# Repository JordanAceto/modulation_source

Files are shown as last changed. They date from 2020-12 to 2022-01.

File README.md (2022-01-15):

# Eurorack Modulation Source



## [SCHEMATIC](https://github.com/JordanAceto/modulation_source/blob/main/main_pcb/construction_docs/modulation_source_schematic.pdf)

## Features:
- Sine and Square wave voltage controlled LFO
- LED indicator shown the LFO speed
- White and Pink noise source
- Sample and Hold
- Convenient normalization
    - LFO square wave normalled to the S&H clock input
    - White noise normalled to the S&H signal input
- There is a pcb front panel, for a cheap and cheerful panel option

## Errata:
- The pink noise gain is a little hot, change R30 to around 39k to bring the pink noise level down if desired

## Status of the project:

Task | Status |
---------|--------------|
Schematic capture | &#9745;
PCB layout | &#9745;
Test build | &#9745;
Safe to order boards| &#9745;

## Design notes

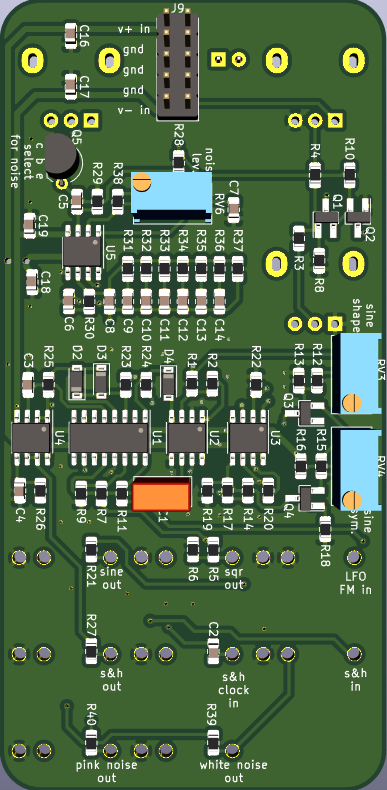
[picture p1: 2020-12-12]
main_pcb/pics/pcb_rear.png

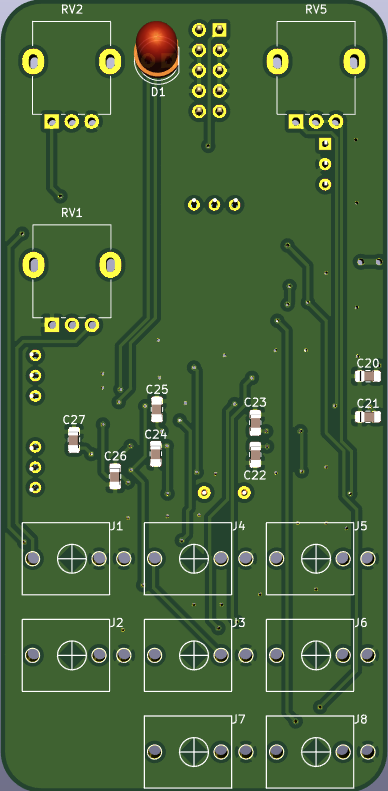
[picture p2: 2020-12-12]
main_pcb/pics/pcb_front.png

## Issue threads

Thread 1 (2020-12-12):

pink noise gain is too high

JordanAceto, 2020-12-12:
The gain of the pink noise filter opamp is too high. reduce R37 so that the peak to peak amplitude of the pink noise is roughly equal to the peak to peak amplitude of the white noise.

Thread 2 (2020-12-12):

LED is a bit close to the rate pot

JordanAceto, 2020-12-12:
When a knob is put on the rate potentiometer it is very close to the LFO indicator LED. Consider moving the LED a smidge if a board rev happens.

JordanAceto, 2022-01-15:
This is fine if you don't use huge knobs, leave as is.

Closed 2022-01-15.

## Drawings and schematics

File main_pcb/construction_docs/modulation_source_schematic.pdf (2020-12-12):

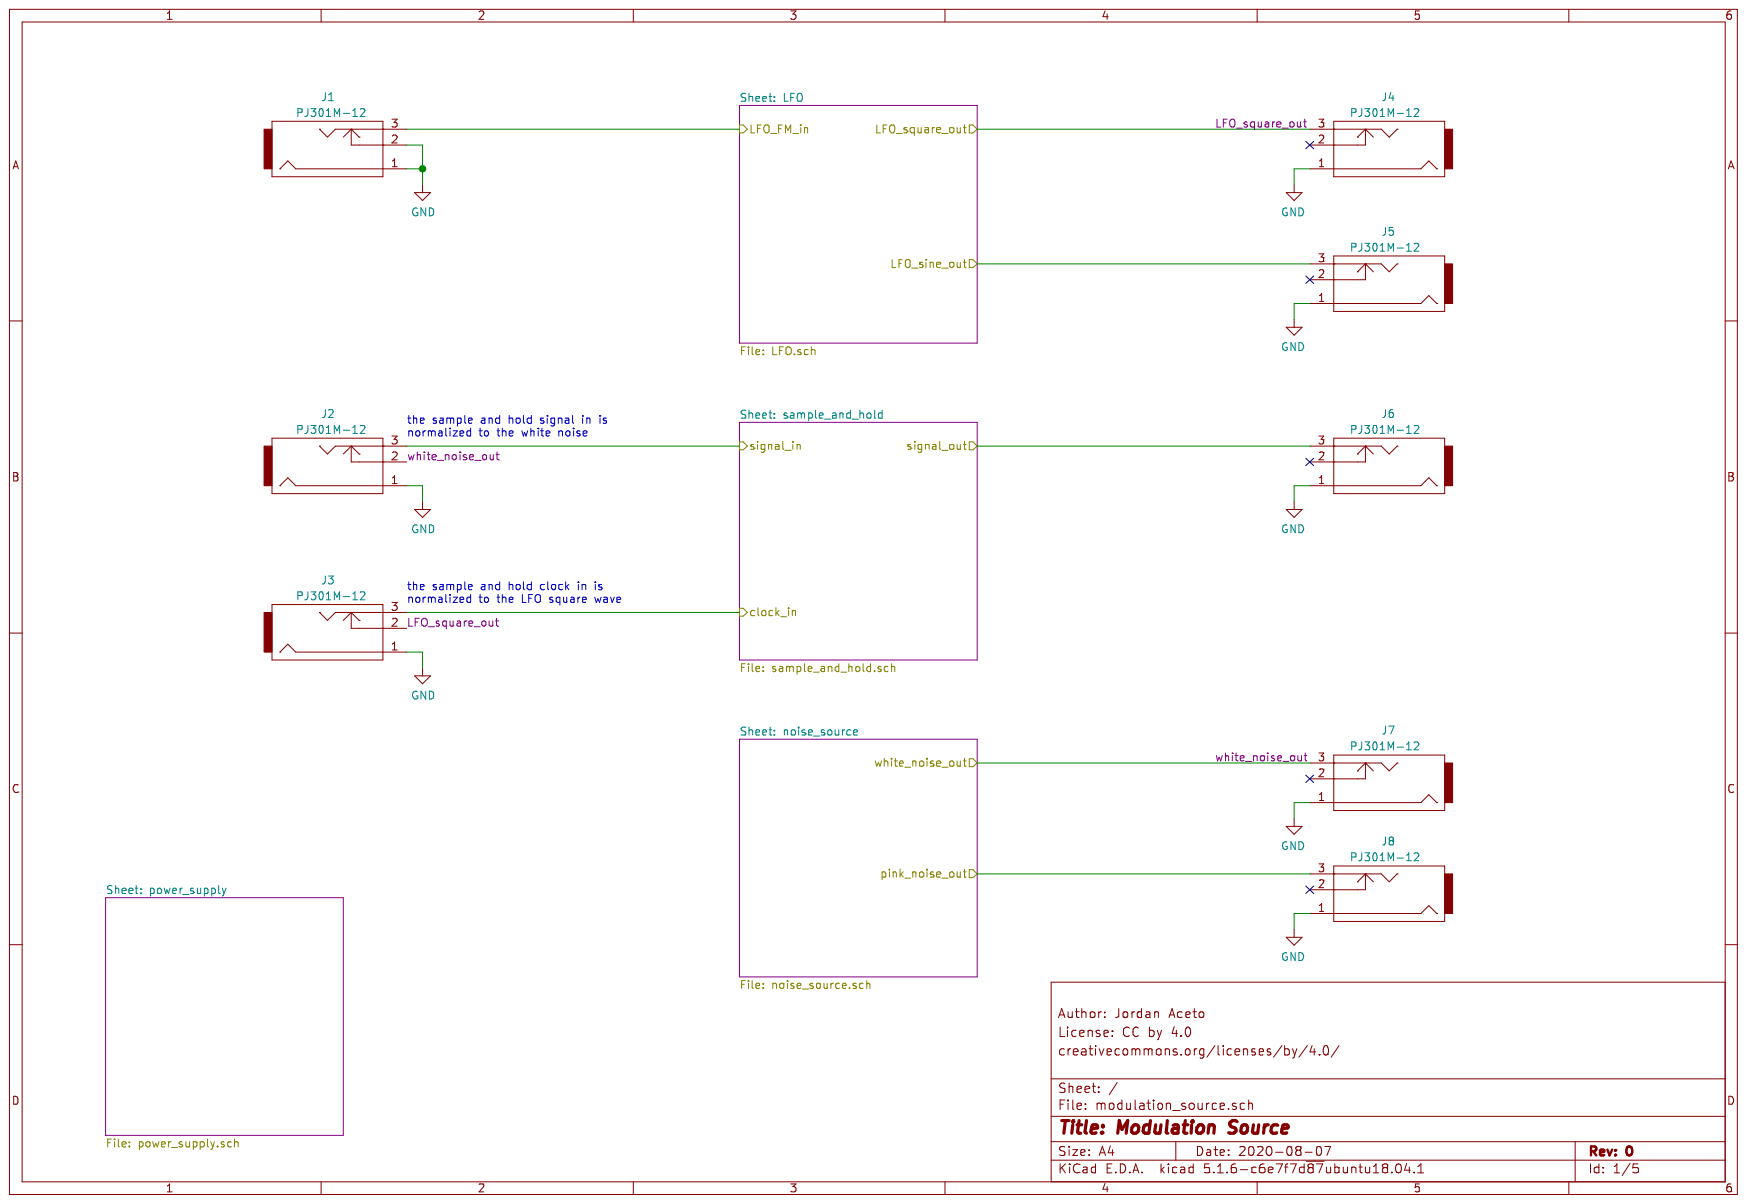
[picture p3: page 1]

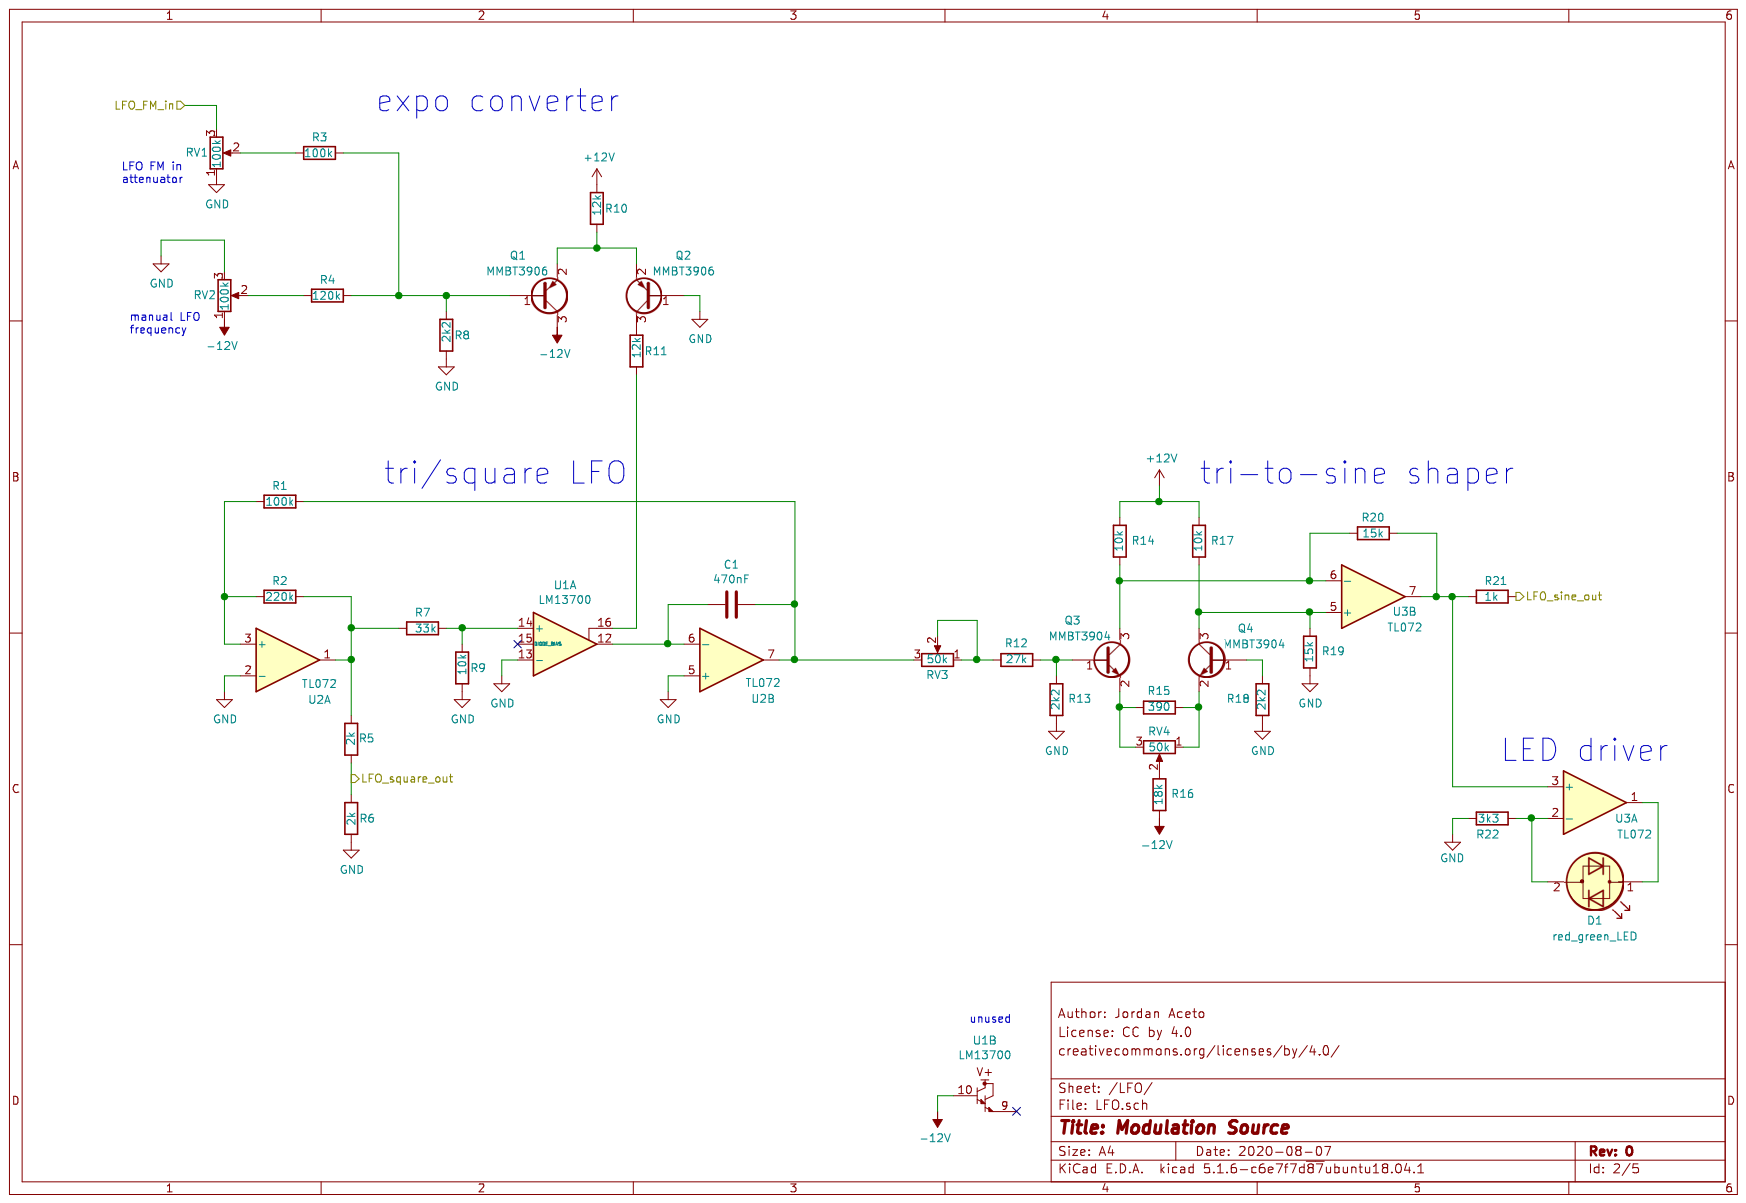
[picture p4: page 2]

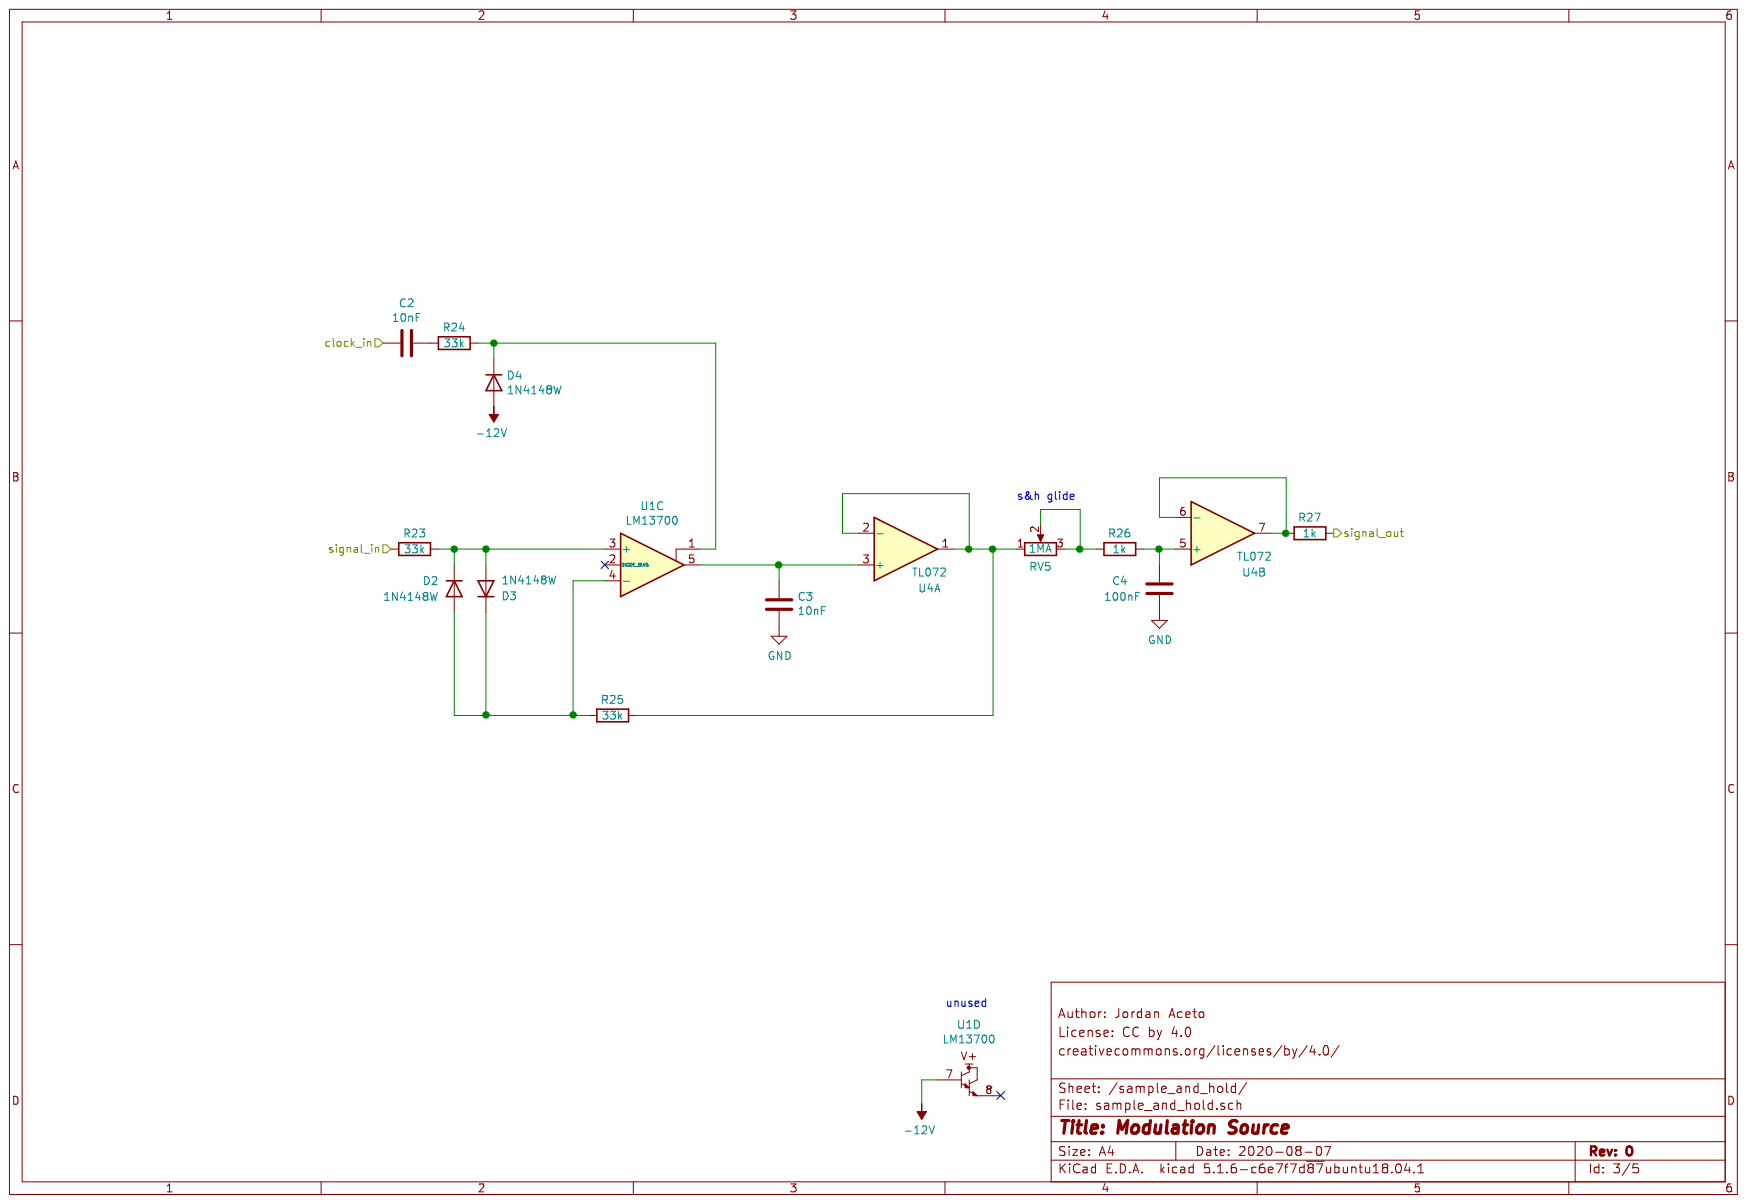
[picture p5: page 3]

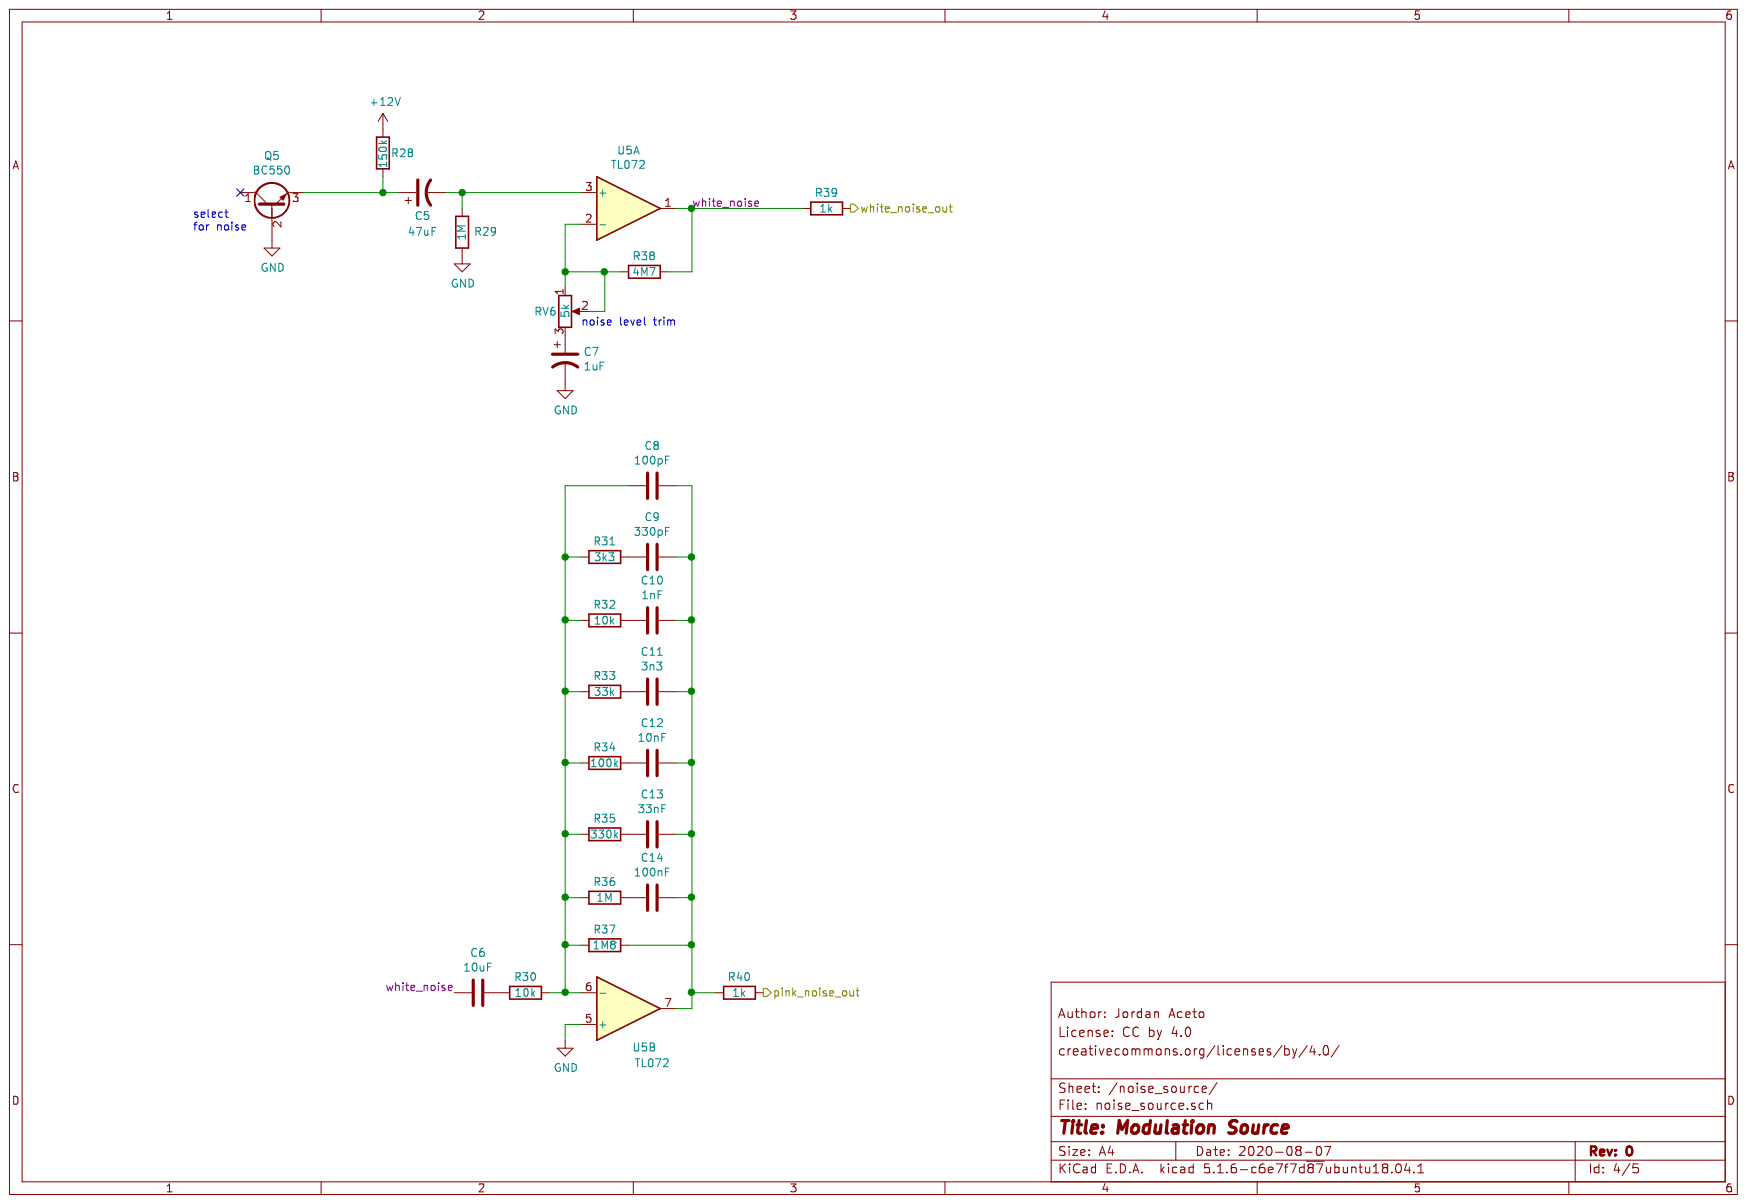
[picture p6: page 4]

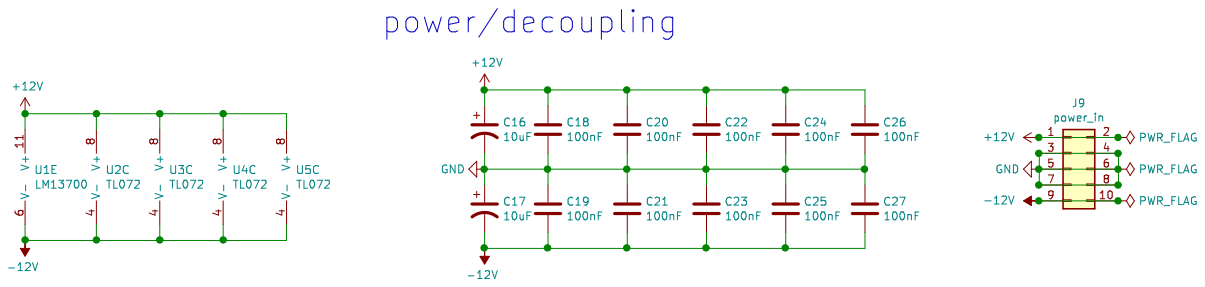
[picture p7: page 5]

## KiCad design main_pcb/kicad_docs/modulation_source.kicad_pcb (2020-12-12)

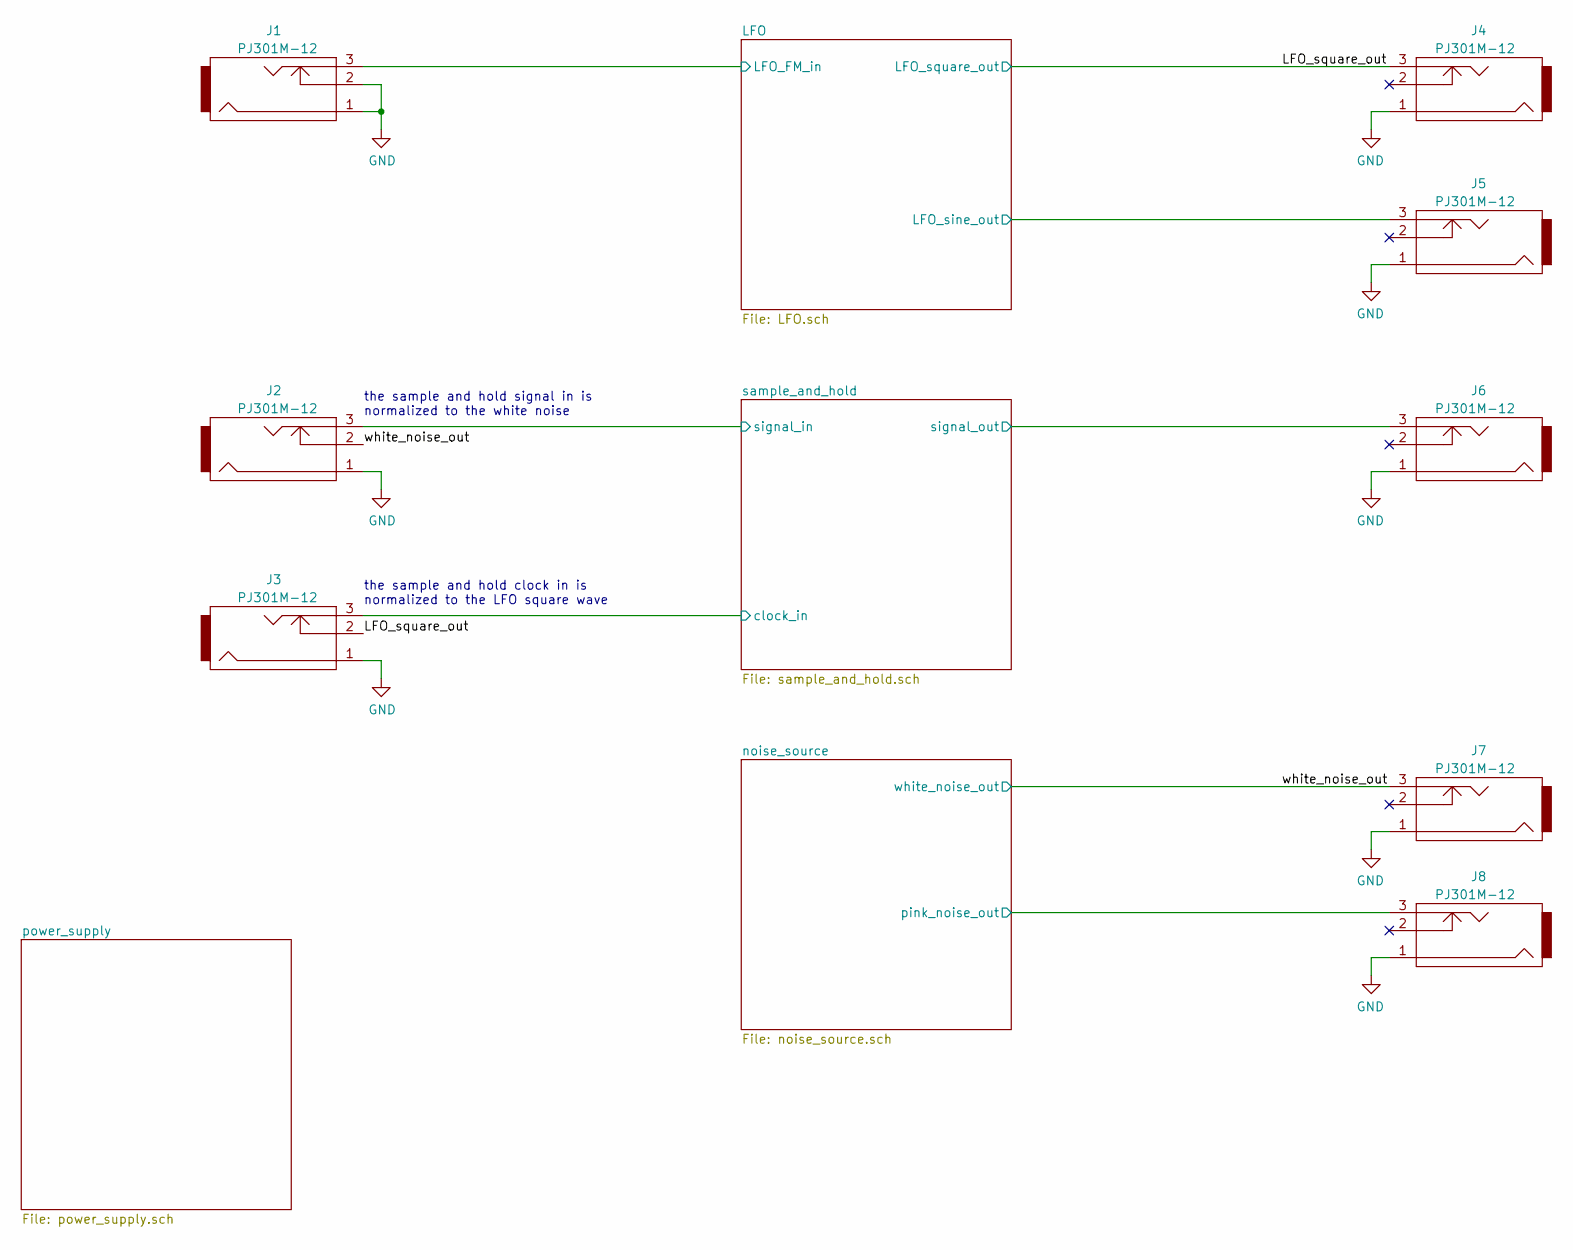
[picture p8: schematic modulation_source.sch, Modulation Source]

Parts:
J1, J2, J3, J4, J5, J6, J7, J8: PJ301M-12

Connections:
/LFO/LFO_FM_in: J1.3; also elsewhere on the board
/LFO/LFO_sine_out: J5.3; also elsewhere on the board
/LFO_square_out: J3.2, J4.3; also elsewhere on the board
/noise_source/pink_noise_out: J8.3; also elsewhere on the board
/sample_and_hold/clock_in: J3.3; also elsewhere on the board
/sample_and_hold/signal_in: J2.3; also elsewhere on the board
/sample_and_hold/signal_out: J6.3; also elsewhere on the board
/white_noise_out: J2.2, J7.3; also elsewhere on the board
GND: J1.1, J1.2, J2.1, J3.1, J4.1, J5.1, J6.1, J7.1, J8.1; also elsewhere on the board

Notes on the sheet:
the sample and hold signal in is normalized to the white noise
the sample and hold clock in is normalized to the LFO square wave

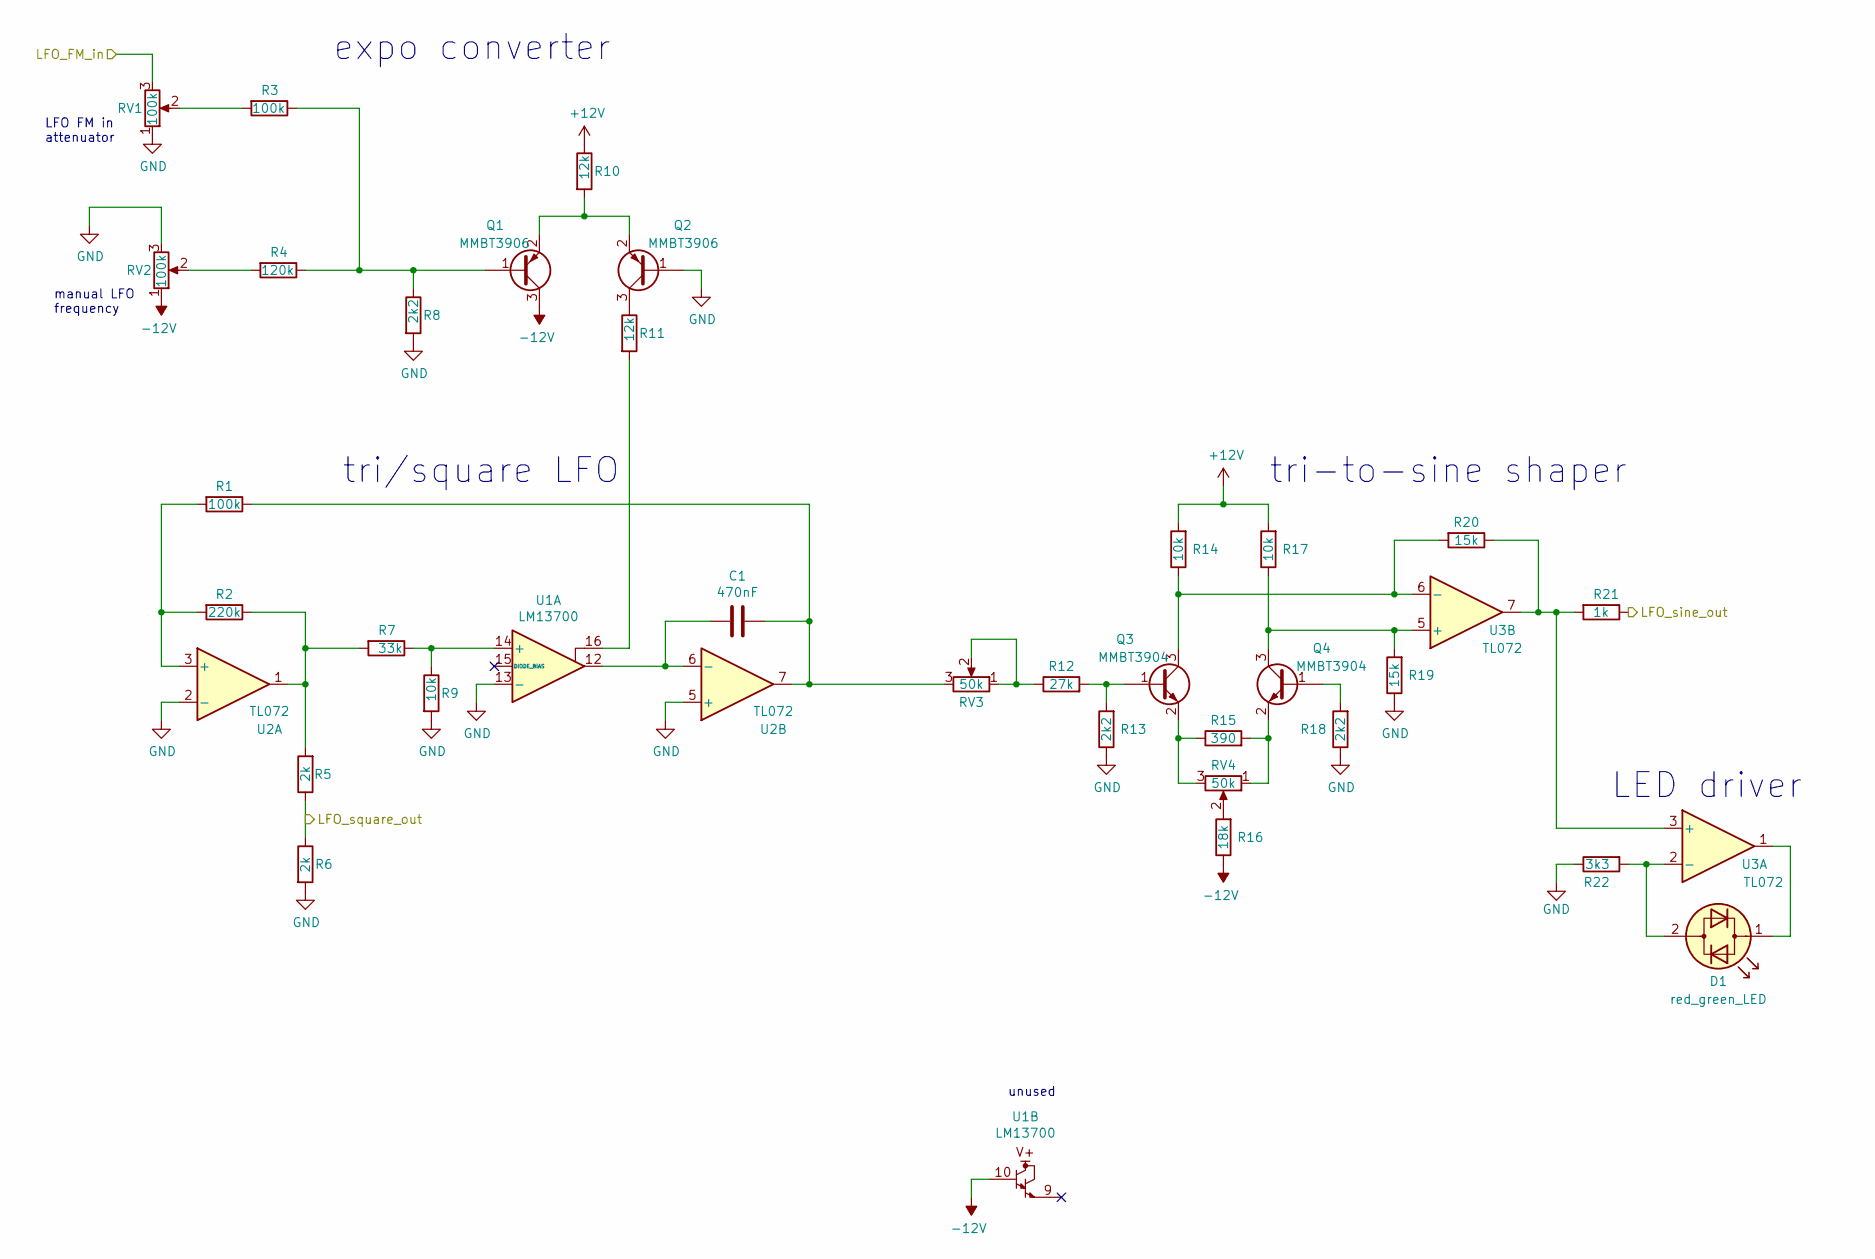
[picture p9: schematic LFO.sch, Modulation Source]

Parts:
C1: 470nF; C_Rect_L7.0mm_W3.5mm_P5.00mm
D1: red_green_LED; LED_D5.0mm
Q1, Q2: MMBT3906; SOT-23_Handsoldering
Q3, Q4: MMBT3904; SOT-23_Handsoldering
R1, R3: 100k; R_0805_2012Metric_Pad1.15x1.40mm_HandSolder
R2: 220k; R_0805_2012Metric_Pad1.15x1.40mm_HandSolder
R4: 120k; R_0805_2012Metric_Pad1.15x1.40mm_HandSolder
R5, R6: 2k; R_0805_2012Metric_Pad1.15x1.40mm_HandSolder
R7: 33k; R_0805_2012Metric_Pad1.15x1.40mm_HandSolder
R8, R13, R18: 2k2; R_0805_2012Metric_Pad1.15x1.40mm_HandSolder
R9, R14, R17: 10k; R_0805_2012Metric_Pad1.15x1.40mm_HandSolder
R10, R11: 12k; R_0805_2012Metric_Pad1.15x1.40mm_HandSolder
R12: 27k; R_0805_2012Metric_Pad1.15x1.40mm_HandSolder
R15: 390; R_0805_2012Metric_Pad1.15x1.40mm_HandSolder
R16: 18k; R_0805_2012Metric_Pad1.15x1.40mm_HandSolder
R19, R20: 15k; R_0805_2012Metric_Pad1.15x1.40mm_HandSolder
R21: 1k; R_0805_2012Metric_Pad1.15x1.40mm_HandSolder
R22: 3k3; R_0805_2012Metric_Pad1.15x1.40mm_HandSolder
RV1, RV2: 100k; Potentiometer_Alpha_RD901F-40-00D_Single_Vertical
RV3, RV4: 50k; Potentiometer_Bourns_3296W_Vertical
U1: LM13700; SOIC-16_3.9x9.9mm_P1.27mm
U2, U3: TL072; SOIC-8_3.9x4.9mm_P1.27mm

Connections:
+12V: R10.1, R14.2, R17.2; also elsewhere on the board
-12V: Q1.3 (C), R16.1, RV2.1, U1.10; also elsewhere on the board
/LFO/LFO_FM_in: RV1.3; also elsewhere on the board
/LFO/LFO_sine_out: R21.1; also elsewhere on the board
/LFO_square_out: R5.1, R6.1; also elsewhere on the board
GND: Q2.1 (B), R6.2, R8.2, R9.2, R13.1, R18.1, R19.1, R22.1, RV1.1, RV2.3, U1.13 (-), U2.2 (-), U2.5 (+); also elsewhere on the board
unnamed: C1.1, R1.1, RV3.3, U2.7
unnamed: C1.2, U1.12, U2.6 (-)
unnamed: D1.1 (KA), U3.1
unnamed: D1.2 (AK), R22.2, U3.2 (-)
unnamed: Q1.1 (B), R3.1, R4.1, R8.1
unnamed: Q1.2 (E), Q2.2 (E), R10.2
unnamed: Q2.3 (C), R11.1
unnamed: Q3.1 (B), R12.2, R13.2
unnamed: Q3.2 (E), R15.1, RV4.3
unnamed: Q3.3 (C), R14.1, R20.2, U3.6 (-)
unnamed: Q4.1 (B), R18.2
unnamed: Q4.2 (E), R15.2, RV4.1
unnamed: Q4.3 (C), R17.1, R19.2, U3.5 (+)
unnamed: R1.2, R2.2, U2.3 (+)
unnamed: R2.1, R5.2, R7.2, U2.1
unnamed: R3.2, RV1.2
unnamed: R4.2, RV2.2
unnamed: R7.1, R9.1, U1.14 (+)
unnamed: R11.2, U1.16
unnamed: R12.1, RV3.1, RV3.2
unnamed: R16.2, RV4.2
unnamed: R20.1, R21.2, U3.3 (+), U3.7

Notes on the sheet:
tri-to-sine shaper
tri/square LFO
expo converter
unused
manual LFO frequency
LFO FM in attenuator
LED driver

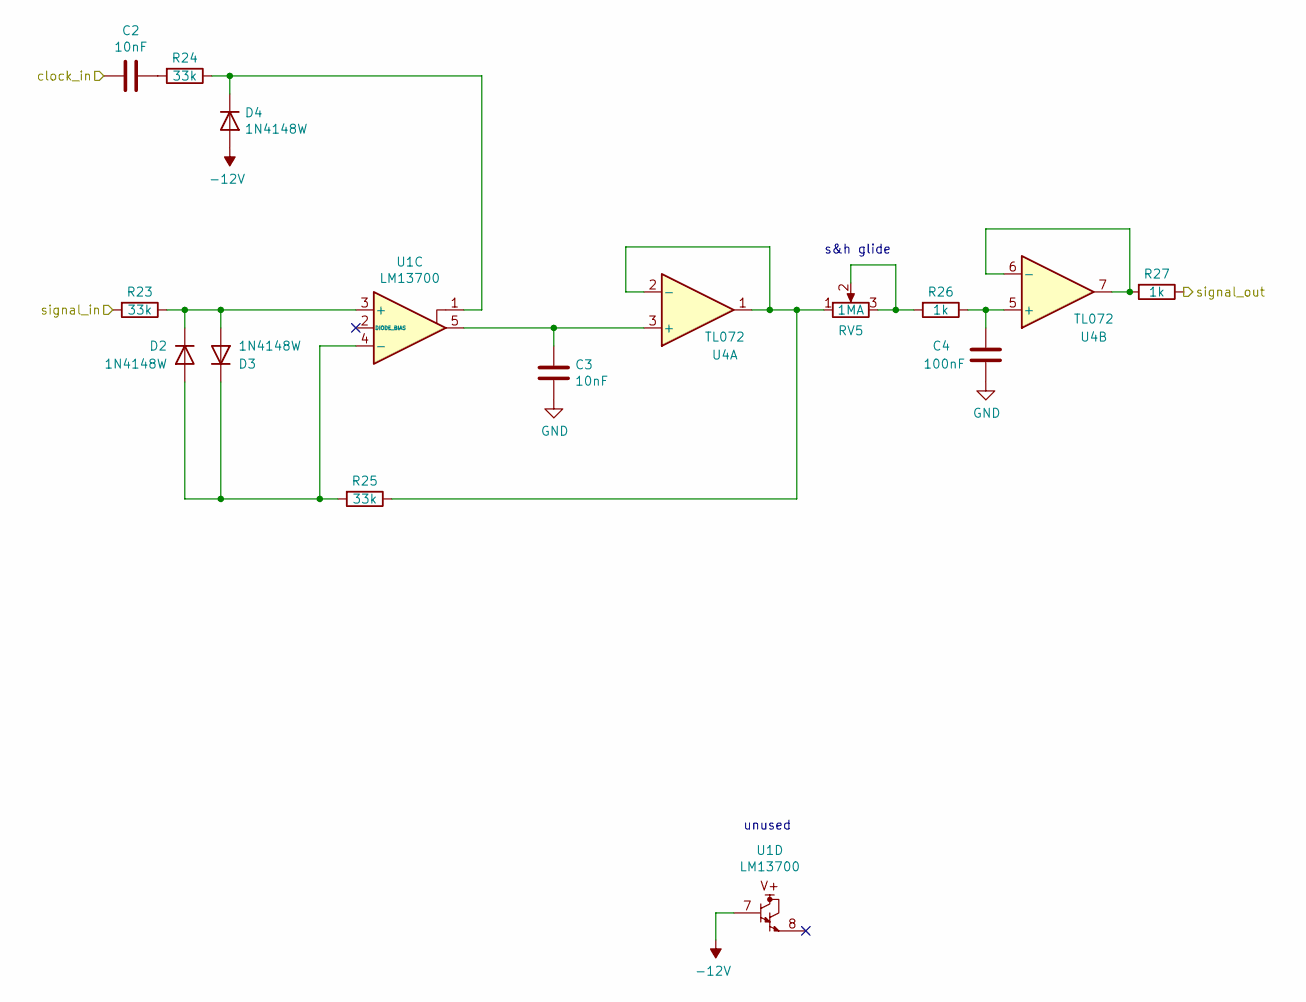
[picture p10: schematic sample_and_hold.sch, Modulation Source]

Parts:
C2, C3: 10nF; C_0805_2012Metric_Pad1.15x1.40mm_HandSolder
C4: 100nF; C_0805_2012Metric_Pad1.15x1.40mm_HandSolder
D2, D3, D4: 1N4148W; D_SOD-123
R23, R24, R25: 33k; R_0805_2012Metric_Pad1.15x1.40mm_HandSolder
R26, R27: 1k; R_0805_2012Metric_Pad1.15x1.40mm_HandSolder
RV5: 1MA; Potentiometer_Alpha_RD901F-40-00D_Single_Vertical
U1: LM13700; SOIC-16_3.9x9.9mm_P1.27mm
U4: TL072; SOIC-8_3.9x4.9mm_P1.27mm

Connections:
-12V: D4.2 (A), U1.7; also elsewhere on the board
/sample_and_hold/clock_in: C2.2; also elsewhere on the board
/sample_and_hold/signal_in: R23.2; also elsewhere on the board
/sample_and_hold/signal_out: R27.1; also elsewhere on the board
GND: C3.1, C4.2; also elsewhere on the board
unnamed: C2.1, R24.2
unnamed: C3.2, U1.5, U4.3 (+)
unnamed: C4.1, R26.1, U4.5 (+)
unnamed: D2.1 (K), D3.2 (A), R23.1, U1.3 (+)
unnamed: D2.2 (A), D3.1 (K), R25.2, U1.4 (-)
unnamed: D4.1 (K), R24.1, U1.1
unnamed: R25.1, RV5.1, U4.1, U4.2 (-)
unnamed: R26.2, RV5.2, RV5.3
unnamed: R27.2, U4.6 (-), U4.7

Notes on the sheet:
s&h glide
unused

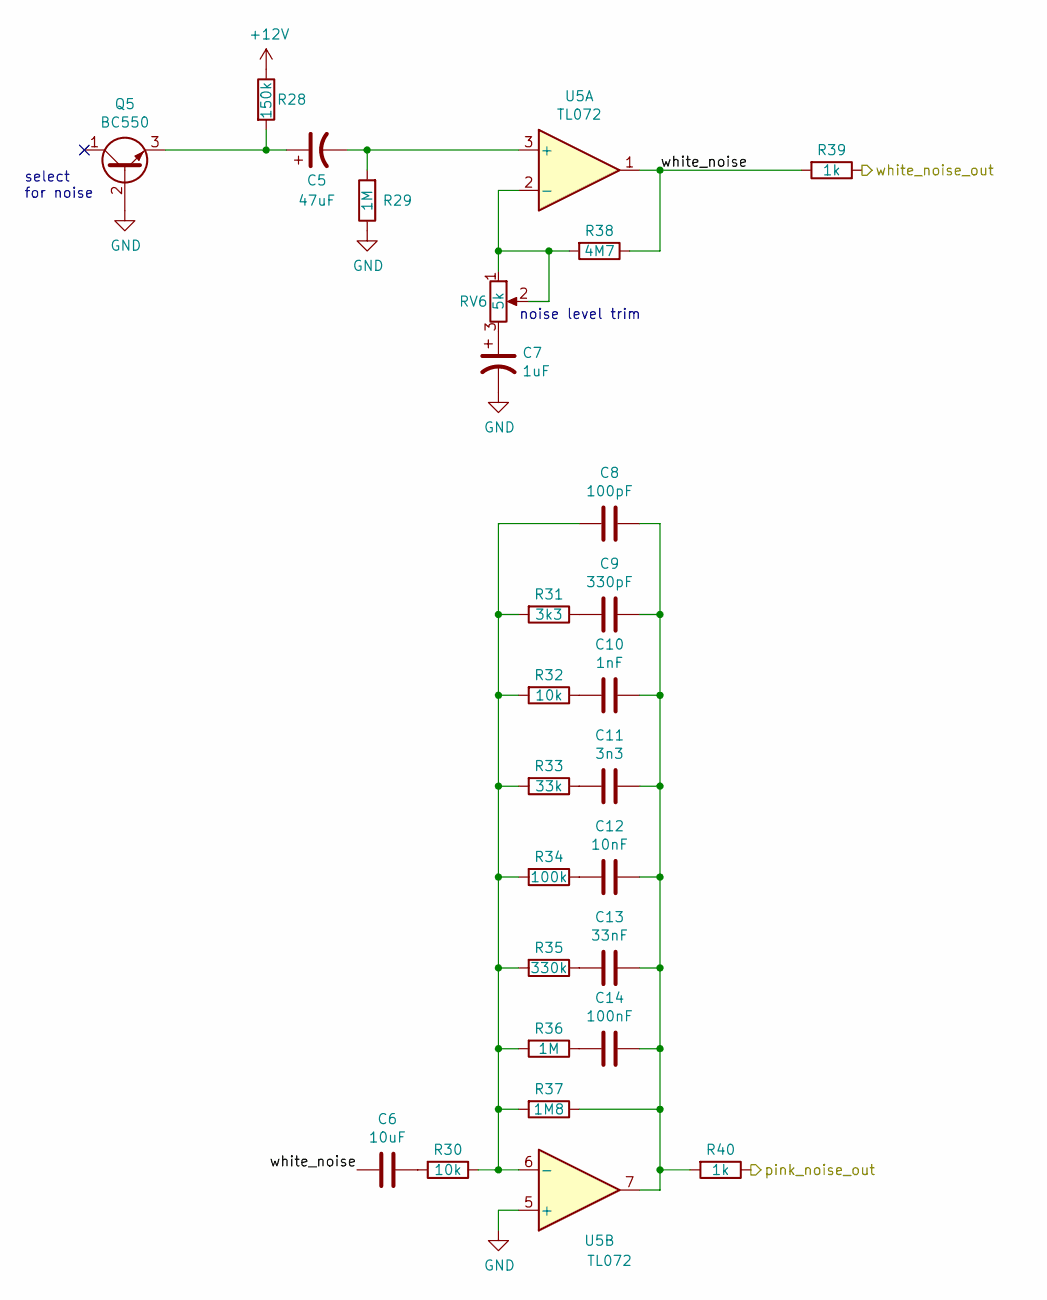
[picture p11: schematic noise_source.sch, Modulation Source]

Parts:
C5: 47uF; C_0805_2012Metric_Pad1.15x1.40mm_HandSolder
C6: 10uF; C_0805_2012Metric_Pad1.15x1.40mm_HandSolder
C7: 1uF; C_0805_2012Metric_Pad1.15x1.40mm_HandSolder
C8: 100pF; C_0805_2012Metric_Pad1.15x1.40mm_HandSolder
C9: 330pF; C_0805_2012Metric_Pad1.15x1.40mm_HandSolder
C10: 1nF; C_0805_2012Metric_Pad1.15x1.40mm_HandSolder
C11: 3n3; C_0805_2012Metric_Pad1.15x1.40mm_HandSolder
C12: 10nF; C_0805_2012Metric_Pad1.15x1.40mm_HandSolder
C13: 33nF; C_0805_2012Metric_Pad1.15x1.40mm_HandSolder
C14: 100nF; C_0805_2012Metric_Pad1.15x1.40mm_HandSolder
Q5: BC550; TO-92_Inline_Wide
R28: 150k; R_0805_2012Metric_Pad1.15x1.40mm_HandSolder
R29, R36: 1M; R_0805_2012Metric_Pad1.15x1.40mm_HandSolder
R30, R32: 10k; R_0805_2012Metric_Pad1.15x1.40mm_HandSolder
R31: 3k3; R_0805_2012Metric_Pad1.15x1.40mm_HandSolder
R33: 33k; R_0805_2012Metric_Pad1.15x1.40mm_HandSolder
R34: 100k; R_0805_2012Metric_Pad1.15x1.40mm_HandSolder
R35: 330k; R_0805_2012Metric_Pad1.15x1.40mm_HandSolder
R37: 1M8; R_0805_2012Metric_Pad1.15x1.40mm_HandSolder
R38: 4M7; R_0805_2012Metric_Pad1.15x1.40mm_HandSolder
R39, R40: 1k; R_0805_2012Metric_Pad1.15x1.40mm_HandSolder
RV6: 5k; Potentiometer_Bourns_3296W_Vertical
U5: TL072; SOIC-8_3.9x4.9mm_P1.27mm

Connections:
+12V: R28.1; also elsewhere on the board
/noise_source/pink_noise_out: R40.1; also elsewhere on the board
/noise_source/white_noise: C6.2, R38.1, R39.2, U5.1
/white_noise_out: R39.1; also elsewhere on the board
GND: C7.2, Q5.2 (B), R29.1, U5.5 (+); also elsewhere on the board
unnamed: C5.1, Q5.3 (E), R28.2
unnamed: C5.2, R29.2, U5.3 (+)
unnamed: C6.1, R30.2
unnamed: C7.1, RV6.3
unnamed: C8.2, R30.1, R31.2, R32.2, R33.2, R34.2, R35.2, R36.2, R37.2, U5.6 (-)
unnamed: C9.2, R31.1
unnamed: C8.1, C9.1, C10.1, C11.1, C12.1, C13.1, C14.1, R37.1, R40.2, U5.7
unnamed: C10.2, R32.1
unnamed: C11.2, R33.1
unnamed: C12.2, R34.1
unnamed: C13.2, R35.1
unnamed: C14.2, R36.1
unnamed: R38.2, RV6.1, RV6.2, U5.2 (-)

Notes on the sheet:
noise level trim
select for noise

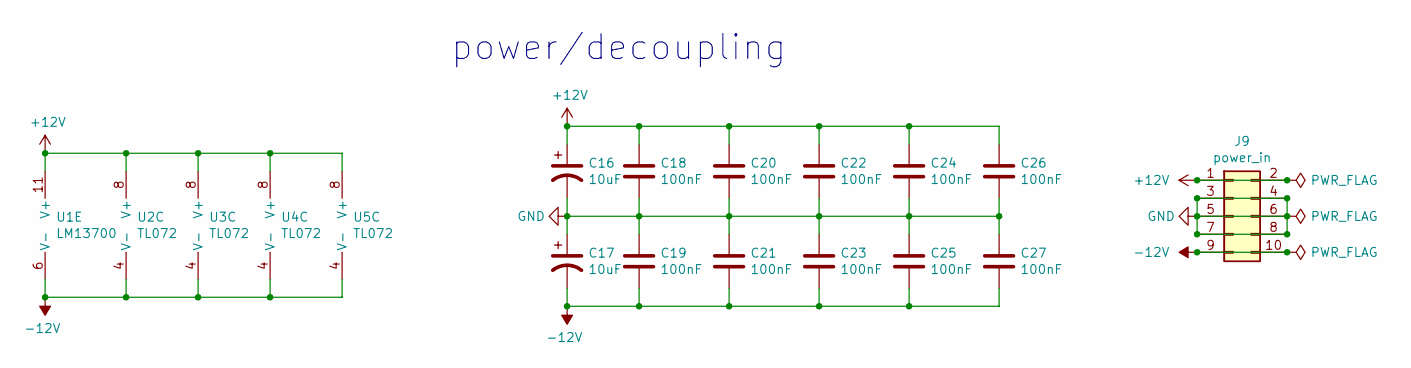
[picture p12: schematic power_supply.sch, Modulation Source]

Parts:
C16, C17: 10uF; C_0805_2012Metric_Pad1.15x1.40mm_HandSolder
C18, C19, C20, C21, C22, C23, C24, C25, C26, C27: 100nF; C_0805_2012Metric_Pad1.15x1.40mm_HandSolder
J9: power_in; PinHeader_2x05_P2.54mm_Vertical
U1: LM13700; SOIC-16_3.9x9.9mm_P1.27mm
U2, U3, U4, U5: TL072; SOIC-8_3.9x4.9mm_P1.27mm

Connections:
+12V: C16.1, C18.1, C20.1, C22.1, C24.1, C26.1, J9.1, J9.2, U1.11 (V+), U2.8 (V+), U3.8 (V+), U4.8 (V+), U5.8 (V+); also elsewhere on the board
-12V: C17.2, C19.2, C21.2, C23.2, C25.2, C27.2, J9.9, J9.10, U1.6 (V-), U2.4 (V-), U3.4 (V-), U4.4 (V-), U5.4 (V-); also elsewhere on the board
GND: C16.2, C17.1, C18.2, C19.1, C20.2, C21.1, C22.2, C23.1, C24.2, C25.1, C26.2, C27.1, J9.3, J9.4, J9.5, J9.6, J9.7, J9.8; also elsewhere on the board

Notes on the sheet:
power/decoupling

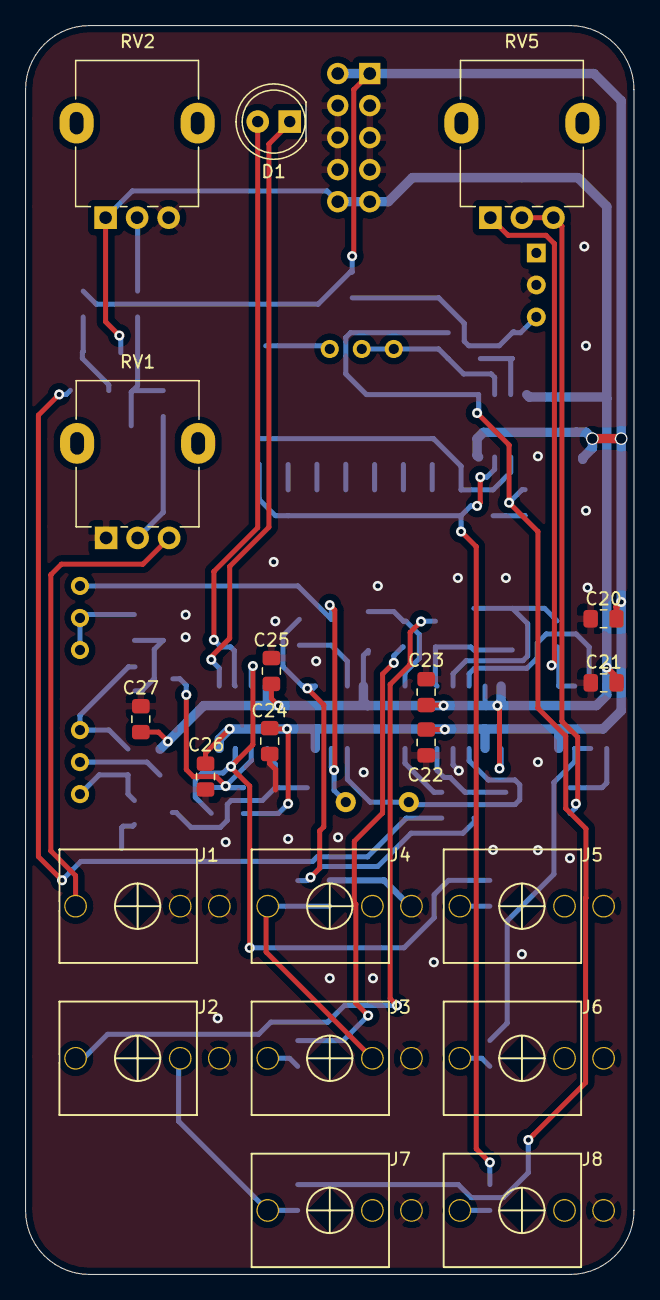
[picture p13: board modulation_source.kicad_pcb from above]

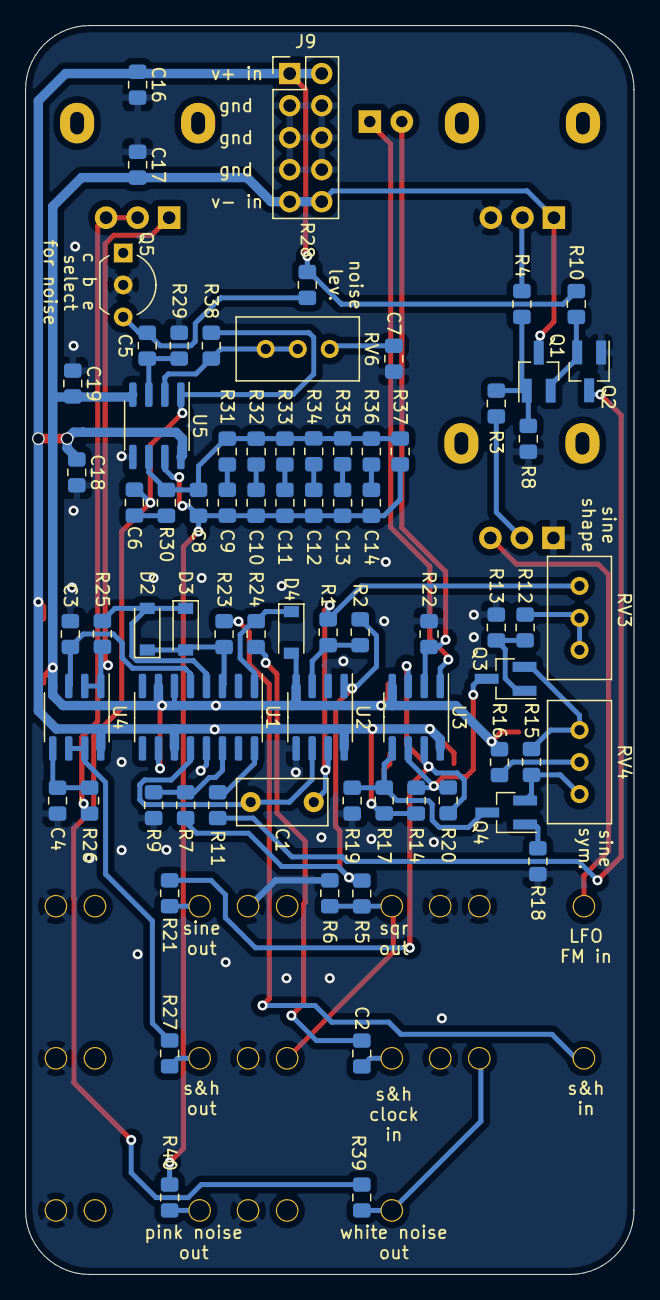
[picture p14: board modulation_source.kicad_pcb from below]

Board: 2 copper layers, 48.3 x 99.1 mm, 95 parts (75 on the bottom side), 56 nets.

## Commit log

2020-12-12 add some rendered pics of the pcb
2022-01-05 add front panel
    [LFO.sch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]

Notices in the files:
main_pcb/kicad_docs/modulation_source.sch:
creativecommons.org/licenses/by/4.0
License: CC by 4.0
